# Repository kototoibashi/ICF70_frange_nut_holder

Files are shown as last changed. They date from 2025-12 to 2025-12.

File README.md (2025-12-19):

# ICF70 ConFlat Flange Nut Holder

真空装置の標準規格である ICF70フランジにおいて、締結時のM6ナットを背後から保持し、レンチ不要での作業を可能にするための3Dプリント用ホルダーです。

## 概要

ICF70フランジの締結作業において、狭いスペースでのナット保持は困難を極めます。本部品はPCD58.7mmのボルト配置に完全に適合し、M6ナットを回り止め状態で固定します。

「ハーフモデル」として設計されているため、既存の配管を外すことなく横から差し込むことができ、メンテナンス性に優れています。
### 仕様 (Specifications)

    適合規格: ICF70 (外径70mm)

    ボルト穴: PCD58.7mm 6H (6穴対応 / 本モデルはハーフのため3穴分)

    対応ナット: M6 六角ナット (二面幅 10mm)

### 設計機能:

        45° Chamfer: 外周エッジに45度の面取りを施し、造形品質と取り扱い時の安全性を向上。

        Half-Cut Design: 半円形状により、クランプや既存配管との干渉を最小限に抑制。

        Parametric: OpenSCADにより、公差や厚みの微調整が可能。

## 使用方法

    icf70_nut_holder.scad を OpenSCAD で開き、必要に応じて公差（nut_width）を調整します。

    STLとして出力し、3Dプリンタで造形します。

    フランジの裏側に本パーツをセットし、M6ナットをポケットに挿入します。

    正面からボルトを締めるだけで、レンチを当てることなく固定が完了します。

# ICF70 ConFlat Flange Nut Holder
This 3D-printed holder secures the M6 nut from behind during tightening of the ICF70 flange, a standard for vacuum equipment, enabling wrench-free operation.

## Overview

When tightening an ICF70 flange, securing the nut in a tight space can be extremely challenging. This part perfectly fits the PCD 58.7mm bolt layout and secures the M6 nut in a non-rotating manner.

Designed as a "half model," it can be inserted from the side without removing the existing piping, simplifying maintenance.
### Specifications

Compliant Standard: ICF70 (Outer Diameter: 70mm)

Bolt Hole: PCD58.7mm 6H (Compatible with 6 holes / This model is half-cut, so only 3 holes are required)

Compatible Nut: M6 Hex Nut (Flat Width: 10mm)

### Design Features:

45° Chamfer: A 45-degree chamfer is applied to the outer edge to improve build quality and safety during handling.

Half-Cut Design: The semicircular shape minimizes interference with clamps and existing piping.

Parametric: Fine-tune tolerances and thickness using OpenSCAD.

## How to Use

Open icf70_nut_holder.scad in OpenSCAD and adjust the tolerance (nut_width) as needed.

Export as an STL file and print using a 3D printer.

Place this part behind the flange and insert an M6 nut into the pocket.

Simply tighten the bolts from the front and you can secure it without using a wrench.

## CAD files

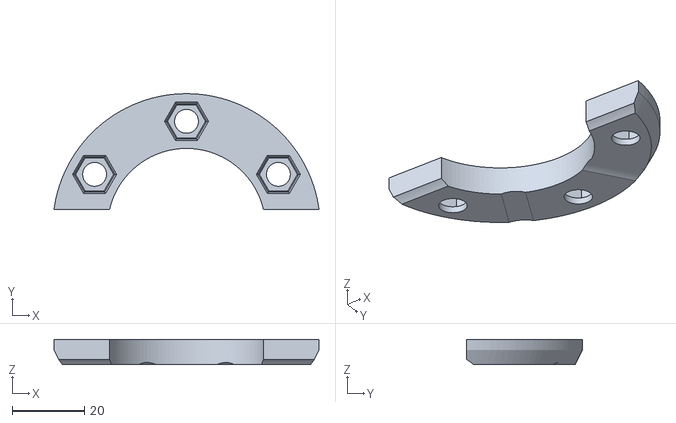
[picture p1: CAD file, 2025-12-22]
icf70 nut holder.stl
73.3 x 32.0 x 7.00

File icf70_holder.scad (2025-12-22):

// ==========================================
// PCD58.7mm 6H M6 Nut Holder (Half & Chamfered)
// ==========================================
// --- パラメータ設定 ---
$fn = 120;             // 解像度
pcd = 58.7;           // ピッチ円直径
num_holes = 6;        // 全周の穴数
nut_width = 9.7;     // M6ナット二面幅　微調整を推奨（公称10mm）
nut_depth = 5.0;      // ナットポケット深さ
bolt_hole = 6.6;      // ボルト貫通穴（公差込 6.6mm）
base_height = 7;     // 全体の厚み
outer_dia = 74.0;     // 外径
chamfer = 4.0;        // 面取り幅
nut_chamfer = 0.5;    // ナット面取り
nut_chamfer2 = 0.3;    // ナット面取り
// --- 統合モジュール ---
intersection() {
    // 1. メインボディ構築
    difference() {
        // 本体形状：面取りを実現するために垂直部と円錐台を結合
        union() {
            cylinder(h = chamfer, d1 = outer_dia - (chamfer * 1), d2 = outer_dia);
            translate([0, 0, chamfer])
            cylinder(h = base_height - chamfer, d = outer_dia);
        }
        // 中心穴（軽量化・軸合わせ）
        translate([0, 0, -0.1])
        cylinder(h = base_height + 0.2, d = pcd - 15);
        // PCD上の6個の穴とナットポケット
        for (i = [0 : num_holes - 1]) {
            angle = i * 360 / num_holes + 30;
            rotate([0, 0, angle])
            translate([pcd / 2, 0, -0.1]) {
                // ボルト穴
                cylinder(h = base_height + 0.2, d = bolt_hole);
                // ナットポケット本体
                translate([0, 0, base_height - nut_depth])
                rotate([0, 0, 30])
                cylinder(h = nut_depth+0.1, d = nut_width / cos(30), $fn = 6);
                // ナットポケット面取り
                translate([0, 0, base_height - nut_depth - nut_chamfer2])
                rotate([0, 0, 30])
                cylinder(h = nut_chamfer2, 
                        d2 = nut_width / cos(30), 
                        d1 = (nut_width - nut_chamfer2 * 2) / cos(30), 
                        $fn = 6);
                // ナット挿入用面取り
                translate([0, 0, base_height - nut_chamfer])
                rotate([0, 0, 30])
                cylinder(h = nut_chamfer + 0.2, 
                        d1 = nut_width / cos(30), 
                        d2 = (nut_width + nut_chamfer * 2) / cos(30), 
                        $fn = 6);
            }
        }
        // 肉抜き 材料削減とビルドプレート剥離性向上
        for (i = [0 : num_holes - 1]) {
            angle = i * 360 / num_holes;
            rotate([0, 0, angle])
            translate([pcd / 2, 0, -0.1]) {
                rotate([90, 0, 90])
                translate([0, -base_height*0.9,-outer_dia])
                cylinder(h=outer_dia*2, r=base_height);
            }
        }
        // 切り込み ビルドプレート剥離性向上
        rotate([90, 0, 90])
        translate([0, -base_height*1,-outer_dia])
        cylinder(h=outer_dia*2, r=base_height*1.4);
    }
    // 2. ハーフカット処理（Y領域の正の方向のみを抽出）
    // 外周に余裕を持たせたバウンディングボックス
    translate([-outer_dia, 5, -0.1])
    cube([outer_dia * 2, outer_dia, base_height + 0.2]);
}
